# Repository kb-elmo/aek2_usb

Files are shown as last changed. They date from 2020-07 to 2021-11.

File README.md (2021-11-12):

# AEK II USB

[][cc-by-nc-sa]
<a href="https://ko-fi.com/kb_elmo">kofibadge</a>

## This project is completed and will not get updated anymore.

#### QMK compatible drop-in replacement PCB for the Apple Extended Keyboard II
The PCB is built entirely with THT parts to keep a somewhat "vintage" look to it and it uses the fullsize 40-pin DIP package ATmega32A.
The controller is placed in the exact same location as the one on the original PCB.




### Partslist
Most of the parts in this list are just examples and they can be replaced with any component with the same specs.  
They don't have to be from any specific manufacturer or brand to work on this board.

The USB breakout PCB/Daughterboard is NOT included in this repo. You will have to find one yourself.  
Pretty much any kind of breakout board that has usable VCC, GND, D+ and D- pins should work for this.  
Example: https://www.adafruit.com/product/1764

|Count|Part|Designator|Octopart URL|
|-|-|-|-|
|1|ATmega32A 40 pin DIP (32L works too)|U1|[Atmega32a-pu](https://octopart.com/atmega32a-pu-microchip-77760288)|
|1|40 pin DIP socket (optional but highly recommended)|U1|[TE Connectivity 1-2199299-5](https://octopart.com/1-2199299-5-te+connectivity-34963610)|
|1|2x3 pin header 2.54mm (for ISP flashing)|AVR1|[Würth 61200621721](https://octopart.com/61200621721-würth+elektronik-32855457)| 
|1|JST PH 2mm 4pin connector + cable|J1, J2|[JST S4B-PH-K-S](https://octopart.com/s4b-ph-k-s+%28lf%29%28sn%29-jst-5373077)|
|1|USB breakout PCB||[Adafruit 1833](https://octopart.com/1833-adafruit+industries-53099556)|
|1|500 mA polyfuse|F1|[Bourns MF-R050](https://octopart.com/mf-r050-bourns-19418)|
|2|6mm momentary push buttons|RESET1, BOOT1|[TE Connectivity 1825910-6](https://octopart.com/1825910-6-te+connectivity-42270338)|
|1|16 MHz quarz crystal|XTAL1|[Raltron AS-16.000-18](https://octopart.com/as-16.000-18-raltron+electronics-973373)|
|1|4.7 uF electrolytic capacitor|C1|[Panasonic ECA-1HM4R7I](https://octopart.com/eca-1hm4r7i-panasonic-39478610)|
|2|100 nF ceramic disk capacitor|C2, C3|[Kemet C315C104M5U5TA](https://octopart.com/c315c104m5u5ta-kemet-83288)|
|2|22 pF ceramic disk capacitor|C4, C5|[Kemet C317C220J1G5TA](https://octopart.com/c317c220j1g5ta-kemet-1747641)|
|1|10 kΩ resistor|R4|[Multicomp MF25 10k](https://octopart.com/mf25+10k-multicomp-2697429)|
|2|68 Ω resistor|R2, R3|[Multicomp MF25 68R](https://octopart.com/mf25+68r-multicomp-5364489)|
|4|1.5 kΩ resistor|R1, R5, R6, R7|[Multicomp MF25 1k5](https://octopart.com/mf25+1k5-multicomp-5372506)|
|3|5mm LED (for the lock indicators)|LED1, LED2, LED3|[Vishay TLHG5400](https://octopart.com/tlhg5400-vishay-39403037)|
|2|3.6 V zener diode (DO-35 BZX55C3V6)|D1, D2|[ON Semiconductor BZX85C3V6](https://octopart.com/bzx85c3v6-on+semiconductor-84409073)|
|105|universal switching diode (DO-35 1N4148)|D3-D107|[ON Semiconductor 1N4148](https://octopart.com/1n4148-on+semiconductor-6807167)|

#### Some pictures of the first finished PCB
(https://i.imgur.com/3325BHB.jpg) (https://i.imgur.com/cYwRUWX.jpg)
(https://i.imgur.com/b2IuvLg.jpg) (https://i.imgur.com/vxiDwE3.jpg)
(https://i.imgur.com/lfABr6a.jpg) (https://i.imgur.com/BY7TV2w.jpg)

---
This work is licensed under a
[Creative Commons Attribution-NonCommercial-ShareAlike 4.0 International License][cc-by-nc-sa].

[][cc-by-nc-sa]

[cc-by-nc-sa]: http://creativecommons.org/licenses/by-nc-sa/4.0/
[cc-by-nc-sa-image]: https://licensebuttons.net/l/by-nc-sa/4.0/88x31.png
[cc-by-nc-sa-shield]: https://img.shields.io/badge/License-CC%20BY--NC--SA%204.0-lightgrey.svg

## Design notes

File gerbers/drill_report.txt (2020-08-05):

Drill report for aek2_usb.kicad_pcb
Created on Wed Aug  5 12:53:25 2020

Copper Layer Stackup:
    =============================================================
    L1 :  F.Cu                      front
    L2 :  B.Cu                      back

Drill file 'aek2_usb.drl' contains
    plated through holes:
    =============================================================
    T1  0.75mm  0.030"  (8 holes)
    T2  0.80mm  0.031"  (280 holes)
    T3  0.90mm  0.035"  (6 holes)
    T4  1.00mm  0.039"  (8 holes)
    T5  1.10mm  0.043"  (8 holes)
    T6  1.47mm  0.058"  (210 holes)
    T7  4.00mm  0.157"  (2 holes)

    Total plated holes count 522

Not plated through holes are merged with plated holes
    unplated through holes:
    =============================================================

    Total unplated holes count 0

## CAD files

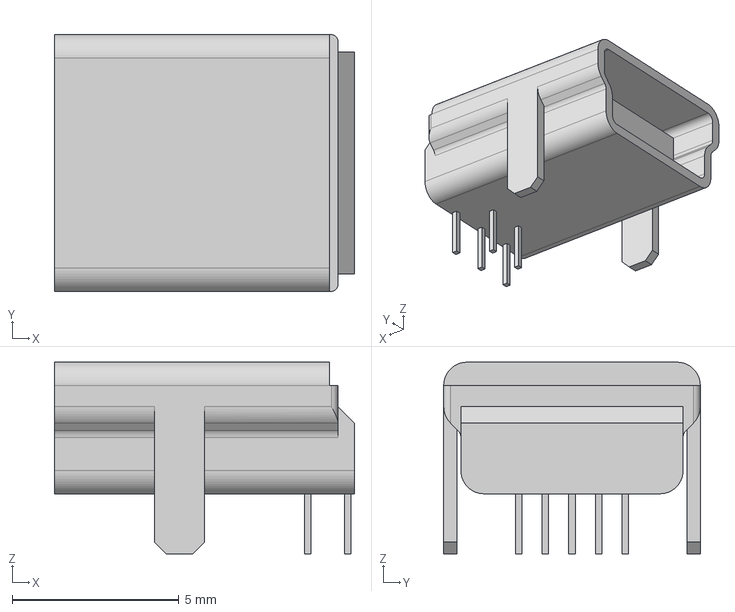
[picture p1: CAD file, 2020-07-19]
custom_parts/Molex-0548190519.step
9.00 x 7.70 x 5.75 mm

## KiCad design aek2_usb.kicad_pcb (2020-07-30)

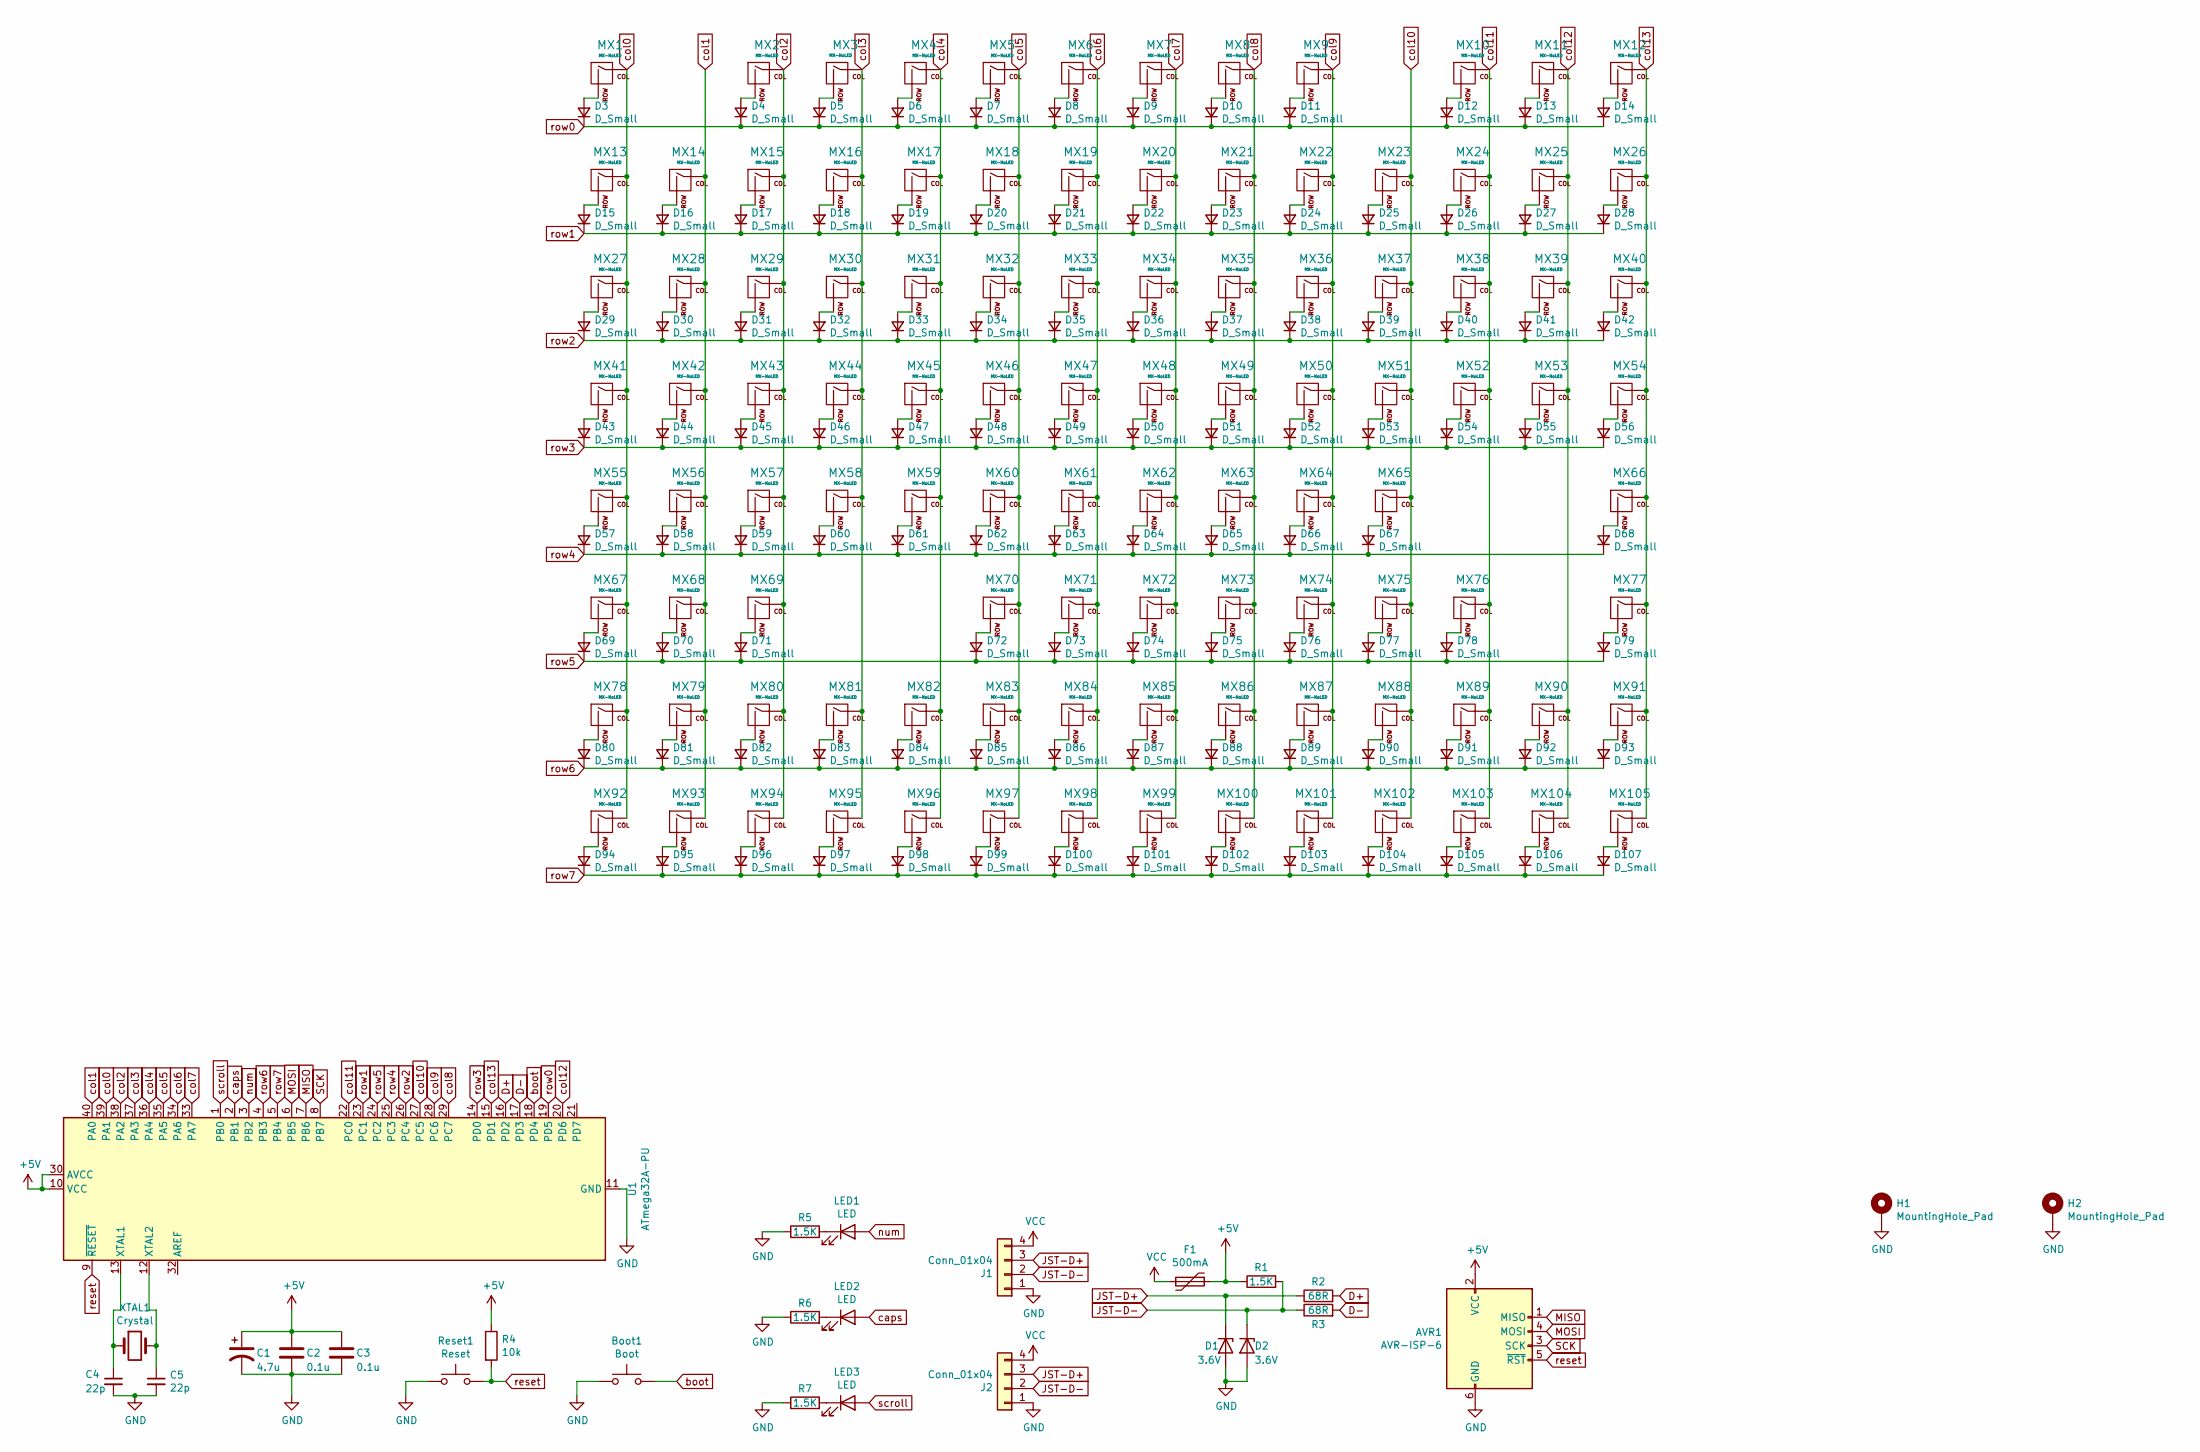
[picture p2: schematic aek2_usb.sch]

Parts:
AVR1: AVR-ISP-6; PinHeader_2x03_P2.54mm_Horizontal
Boot1: Boot; SW_PUSH_6mm
C1: 4.7u; CP_Radial_D5.0mm_P2.50mm
C2, C3: 0.1u; C_Disc_D3.0mm_W2.0mm_P2.50mm
C4, C5: 22p; C_Disc_D6.0mm_W2.5mm_P5.00mm
D1, D2: 3.6V; D_DO-35_SOD27_P7.62mm_Horizontal
D3, D4, D5, D6, D7, D8, D9, D10, D11, D12, D13, D14, D15, D16, D17, D18, D19, D20, D21, D22, D23, D24, D25, D26, D27, D28, D29, D30, D31, D32, D33, D34, D35, D36, D37, D38, D39, D40, D41, D42, D43, D44, D45, D46, D47, D48, D49, D50, D51, D52, D53, D54, D55, D56, D57, D58, D59, D60, D61, D62, D63, D64, D65, D66, D67, D68, D69, D70, D71, D72, D73, D74, D75, D76, D77, D78, D79, D80, D81, D82, D83, D84, D85, D86, D87, D88, D89, D90, D91, D92, D93, D94, D95, D96, D97, D98, D99, D100, D101, D102, D103, D104, D105, D106, D107: D_Small; D_DO-35_SOD27_P7.62mm_Horizontal
F1: 500mA; Fuse_Littelfuse_395Series
H1, H2: MountingHole_Pad; screw-hole
J1, J2: Conn_01x04; JST_PH_S4B-PH-K_1x04_P2.00mm_Horizontal
LED1, LED2, LED3: LED; LED_D5.0mm
MX1, MX2, MX3, MX4, MX5, MX6, MX7, MX8, MX9, MX10, MX11, MX12, MX13, MX14, MX15, MX16, MX17, MX18, MX19, MX20, MX21, MX22, MX23, MX24, MX25, MX28, MX29, MX30, MX31, MX32, MX33, MX34, MX35, MX36, MX37, MX38, MX39, MX42, MX43, MX44, MX45, MX46, MX47, MX48, MX49, MX50, MX51, MX52, MX53, MX56, MX57, MX58, MX59, MX60, MX61, MX62, MX63, MX64, MX65, MX70, MX71, MX72, MX73, MX74, MX78, MX79, MX80, MX81, MX82, MX83, MX84, MX85, MX86, MX87, MX88, MX89, MX90, MX91, MX92, MX93, MX94, MX95, MX96, MX97, MX98, MX99, MX101, MX103, MX104, MX105: MX-NoLED; ALPS-1U
MX26, MX100, MX102: MX-NoLED; ALPS-2U
MX27, MX40, MX67, MX69, MX75, MX77: MX-NoLED; ALPS-1.5U
MX41: MX-NoLED; ALPS-1.75U
MX54, MX55: MX-NoLED; ALPS-2.25U
MX66: MX-NoLED; ALPS-2.75U
MX68, MX76: MX-NoLED; ALPS-1.25U
R1, R5, R6, R7: 1.5K; R_Axial_DIN0207_L6.3mm_D2.5mm_P10.16mm_Horizontal
R2, R3: 68R; R_Axial_DIN0207_L6.3mm_D2.5mm_P10.16mm_Horizontal
R4: 10k; R_Axial_DIN0207_L6.3mm_D2.5mm_P10.16mm_Horizontal
Reset1: Reset; SW_PUSH_6mm
U1: ATmega32A-PU; DIP-40_W15.24mm_Socket
XTAL1: Crystal; Crystal_HC49-4H_Vertical

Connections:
+5V: AVR1.2 (VCC), C1.1, C2.1, C3.1, F1.1, R1.1, R4.1, U1.10 (VCC), U1.30 (AVCC)
D+: R2.2, U1.16 (PD2)
D-: R3.2, U1.17 (PD3)
GND: AVR1.6 (GND), Boot1.1, C1.2, C2.2, C3.2, C4.2, C5.2, D1.2 (A), D2.2 (A), H1.1, H2.1, J1.1, J2.1, R5.1, R6.1, R7.1, Reset1.1, U1.11 (GND), U1.31 (GND)
JST-D+: D1.1 (K), J1.3, J2.3, R2.1
JST-D-: D2.1 (K), J1.2, J2.2, R1.2, R3.1
MISO: AVR1.1 (MISO), U1.7 (PB6)
MOSI: AVR1.4 (MOSI), U1.6 (PB5)
unnamed: C4.1, U1.13 (XTAL1), XTAL1.1
unnamed: C5.1, U1.12 (XTAL2), XTAL1.2
unnamed: D3.2 (A), MX1.2 (ROW)
unnamed: D4.2 (A), MX2.2 (ROW)
unnamed: D5.2 (A), MX3.2 (ROW)
unnamed: D6.2 (A), MX4.2 (ROW)
unnamed: D7.2 (A), MX5.2 (ROW)
unnamed: D8.2 (A), MX6.2 (ROW)
unnamed: D9.2 (A), MX7.2 (ROW)
unnamed: D10.2 (A), MX8.2 (ROW)
unnamed: D11.2 (A), MX9.2 (ROW)
unnamed: D12.2 (A), MX10.2 (ROW)
unnamed: D13.2 (A), MX11.2 (ROW)
unnamed: D14.2 (A), MX12.2 (ROW)
unnamed: D15.2 (A), MX13.2 (ROW)
unnamed: D16.2 (A), MX14.2 (ROW)
unnamed: D17.2 (A), MX15.2 (ROW)
unnamed: D18.2 (A), MX16.2 (ROW)
unnamed: D19.2 (A), MX17.2 (ROW)
unnamed: D20.2 (A), MX18.2 (ROW)
unnamed: D21.2 (A), MX19.2 (ROW)
unnamed: D22.2 (A), MX20.2 (ROW)
unnamed: D23.2 (A), MX21.2 (ROW)
unnamed: D24.2 (A), MX22.2 (ROW)
unnamed: D25.2 (A), MX23.2 (ROW)
unnamed: D26.2 (A), MX24.2 (ROW)
unnamed: D27.2 (A), MX25.2 (ROW)
unnamed: D28.2 (A), MX26.2 (ROW)
unnamed: D29.2 (A), MX27.2 (ROW)
unnamed: D30.2 (A), MX28.2 (ROW)
unnamed: D31.2 (A), MX29.2 (ROW)
unnamed: D32.2 (A), MX30.2 (ROW)
unnamed: D33.2 (A), MX31.2 (ROW)
unnamed: D34.2 (A), MX32.2 (ROW)
unnamed: D35.2 (A), MX33.2 (ROW)
unnamed: D36.2 (A), MX34.2 (ROW)
unnamed: D37.2 (A), MX35.2 (ROW)
unnamed: D38.2 (A), MX36.2 (ROW)
unnamed: D39.2 (A), MX37.2 (ROW)
unnamed: D40.2 (A), MX38.2 (ROW)
unnamed: D41.2 (A), MX39.2 (ROW)
unnamed: D42.2 (A), MX40.2 (ROW)
unnamed: D43.2 (A), MX41.2 (ROW)
unnamed: D44.2 (A), MX42.2 (ROW)
unnamed: D45.2 (A), MX43.2 (ROW)
unnamed: D46.2 (A), MX44.2 (ROW)
unnamed: D47.2 (A), MX45.2 (ROW)
unnamed: D48.2 (A), MX46.2 (ROW)
unnamed: D49.2 (A), MX47.2 (ROW)
unnamed: D50.2 (A), MX48.2 (ROW)
unnamed: D51.2 (A), MX49.2 (ROW)
unnamed: D52.2 (A), MX50.2 (ROW)
unnamed: D53.2 (A), MX51.2 (ROW)
unnamed: D54.2 (A), MX52.2 (ROW)
unnamed: D55.2 (A), MX53.2 (ROW)
unnamed: D56.2 (A), MX54.2 (ROW)
unnamed: D57.2 (A), MX55.2 (ROW)
unnamed: D58.2 (A), MX56.2 (ROW)
unnamed: D59.2 (A), MX57.2 (ROW)
unnamed: D60.2 (A), MX58.2 (ROW)
unnamed: D61.2 (A), MX59.2 (ROW)
unnamed: D62.2 (A), MX60.2 (ROW)
unnamed: D63.2 (A), MX61.2 (ROW)
unnamed: D64.2 (A), MX62.2 (ROW)
unnamed: D65.2 (A), MX63.2 (ROW)
unnamed: D66.2 (A), MX64.2 (ROW)
unnamed: D67.2 (A), MX65.2 (ROW)
unnamed: D68.2 (A), MX66.2 (ROW)
unnamed: D69.2 (A), MX67.2 (ROW)
unnamed: D70.2 (A), MX68.2 (ROW)
unnamed: D71.2 (A), MX69.2 (ROW)
unnamed: D72.2 (A), MX70.2 (ROW)
unnamed: D73.2 (A), MX71.2 (ROW)
unnamed: D74.2 (A), MX72.2 (ROW)
unnamed: D75.2 (A), MX73.2 (ROW)
unnamed: D76.2 (A), MX74.2 (ROW)
unnamed: D77.2 (A), MX75.2 (ROW)
unnamed: D78.2 (A), MX76.2 (ROW)
unnamed: D79.2 (A), MX77.2 (ROW)
unnamed: D80.2 (A), MX78.2 (ROW)
unnamed: D81.2 (A), MX79.2 (ROW)
unnamed: D82.2 (A), MX80.2 (ROW)
unnamed: D83.2 (A), MX81.2 (ROW)
unnamed: D84.2 (A), MX82.2 (ROW)
unnamed: D85.2 (A), MX83.2 (ROW)
unnamed: D86.2 (A), MX84.2 (ROW)
unnamed: D87.2 (A), MX85.2 (ROW)
unnamed: D88.2 (A), MX86.2 (ROW)
unnamed: D89.2 (A), MX87.2 (ROW)
unnamed: D90.2 (A), MX88.2 (ROW)
unnamed: D91.2 (A), MX89.2 (ROW)
unnamed: D92.2 (A), MX90.2 (ROW)
unnamed: D93.2 (A), MX91.2 (ROW)
unnamed: D94.2 (A), MX92.2 (ROW)
unnamed: D95.2 (A), MX93.2 (ROW)
unnamed: D96.2 (A), MX94.2 (ROW)
unnamed: D97.2 (A), MX95.2 (ROW)
unnamed: D98.2 (A), MX96.2 (ROW)
unnamed: D99.2 (A), MX97.2 (ROW)
unnamed: D100.2 (A), MX98.2 (ROW)
unnamed: D101.2 (A), MX99.2 (ROW)
unnamed: D102.2 (A), MX100.2 (ROW)
unnamed: D103.2 (A), MX101.2 (ROW)
unnamed: D104.2 (A), MX102.2 (ROW)
unnamed: D105.2 (A), MX103.2 (ROW)
unnamed: D106.2 (A), MX104.2 (ROW)
unnamed: D107.2 (A), MX105.2 (ROW)
unnamed: LED1.1 (K), R5.2
unnamed: LED2.1 (K), R6.2
unnamed: LED3.1 (K), R7.2
SCK: AVR1.3 (SCK), U1.8 (PB7)
VCC: F1.2, J1.4, J2.4
boot: Boot1.2, U1.18 (PD4)
caps: LED2.2 (A), U1.2 (PB1)
col0: MX1.1 (COL), MX13.1 (COL), MX27.1 (COL), MX41.1 (COL), MX55.1 (COL), MX67.1 (COL), MX78.1 (COL), MX92.1 (COL), U1.39 (PA1)
col1: MX14.1 (COL), MX28.1 (COL), MX42.1 (COL), MX56.1 (COL), MX68.1 (COL), MX79.1 (COL), MX93.1 (COL), U1.40 (PA0)
col2: MX2.1 (COL), MX15.1 (COL), MX29.1 (COL), MX43.1 (COL), MX57.1 (COL), MX69.1 (COL), MX80.1 (COL), MX94.1 (COL), U1.38 (PA2)
col3: MX3.1 (COL), MX16.1 (COL), MX30.1 (COL), MX44.1 (COL), MX58.1 (COL), MX81.1 (COL), MX95.1 (COL), U1.37 (PA3)
col4: MX4.1 (COL), MX17.1 (COL), MX31.1 (COL), MX45.1 (COL), MX59.1 (COL), MX82.1 (COL), MX96.1 (COL), U1.36 (PA4)
col5: MX5.1 (COL), MX18.1 (COL), MX32.1 (COL), MX46.1 (COL), MX60.1 (COL), MX70.1 (COL), MX83.1 (COL), MX97.1 (COL), U1.35 (PA5)
col6: MX6.1 (COL), MX19.1 (COL), MX33.1 (COL), MX47.1 (COL), MX61.1 (COL), MX71.1 (COL), MX84.1 (COL), MX98.1 (COL), U1.34 (PA6)
col7: MX7.1 (COL), MX20.1 (COL), MX34.1 (COL), MX48.1 (COL), MX62.1 (COL), MX72.1 (COL), MX85.1 (COL), MX99.1 (COL), U1.33 (PA7)
col8: MX8.1 (COL), MX21.1 (COL), MX35.1 (COL), MX49.1 (COL), MX63.1 (COL), MX73.1 (COL), MX86.1 (COL), MX100.1 (COL), U1.29 (PC7)
col9: MX9.1 (COL), MX22.1 (COL), MX36.1 (COL), MX50.1 (COL), MX64.1 (COL), MX74.1 (COL), MX87.1 (COL), MX101.1 (COL), U1.28 (PC6)
col10: MX23.1 (COL), MX37.1 (COL), MX51.1 (COL), MX65.1 (COL), MX75.1 (COL), MX88.1 (COL), MX102.1 (COL), U1.27 (PC5)
col11: MX10.1 (COL), MX24.1 (COL), MX38.1 (COL), MX52.1 (COL), MX76.1 (COL), MX89.1 (COL), MX103.1 (COL), U1.22 (PC0)
col12: MX11.1 (COL), MX25.1 (COL), MX39.1 (COL), MX53.1 (COL), MX90.1 (COL), MX104.1 (COL), U1.20 (PD6)
col13: MX12.1 (COL), MX26.1 (COL), MX40.1 (COL), MX54.1 (COL), MX66.1 (COL), MX77.1 (COL), MX91.1 (COL), MX105.1 (COL), U1.15 (PD1)
num: LED1.2 (A), U1.3 (PB2)
reset: AVR1.5 (~RST), R4.2, Reset1.2, U1.9 (~RESET)
row0: D3.1 (K), D4.1 (K), D5.1 (K), D6.1 (K), D7.1 (K), D8.1 (K), D9.1 (K), D10.1 (K), D11.1 (K), D12.1 (K), D13.1 (K), D14.1 (K), U1.19 (PD5)
row1: D15.1 (K), D16.1 (K), D17.1 (K), D18.1 (K), D19.1 (K), D20.1 (K), D21.1 (K), D22.1 (K), D23.1 (K), D24.1 (K), D25.1 (K), D26.1 (K), D27.1 (K), D28.1 (K), U1.23 (PC1)
row2: D29.1 (K), D30.1 (K), D31.1 (K), D32.1 (K), D33.1 (K), D34.1 (K), D35.1 (K), D36.1 (K), D37.1 (K), D38.1 (K), D39.1 (K), D40.1 (K), D41.1 (K), D42.1 (K), U1.26 (PC4)
row3: D43.1 (K), D44.1 (K), D45.1 (K), D46.1 (K), D47.1 (K), D48.1 (K), D49.1 (K), D50.1 (K), D51.1 (K), D52.1 (K), D53.1 (K), D54.1 (K), D55.1 (K), D56.1 (K), U1.14 (PD0)
row4: D57.1 (K), D58.1 (K), D59.1 (K), D60.1 (K), D61.1 (K), D62.1 (K), D63.1 (K), D64.1 (K), D65.1 (K), D66.1 (K), D67.1 (K), D68.1 (K), U1.25 (PC3)
row5: D69.1 (K), D70.1 (K), D71.1 (K), D72.1 (K), D73.1 (K), D74.1 (K), D75.1 (K), D76.1 (K), D77.1 (K), D78.1 (K), D79.1 (K), U1.24 (PC2)
row6: D80.1 (K), D81.1 (K), D82.1 (K), D83.1 (K), D84.1 (K), D85.1 (K), D86.1 (K), D87.1 (K), D88.1 (K), D89.1 (K), D90.1 (K), D91.1 (K), D92.1 (K), D93.1 (K), U1.4 (PB3)
row7: D94.1 (K), D95.1 (K), D96.1 (K), D97.1 (K), D98.1 (K), D99.1 (K), D100.1 (K), D101.1 (K), D102.1 (K), D103.1 (K), D104.1 (K), D105.1 (K), D106.1 (K), D107.1 (K), U1.5 (PB4)
scroll: LED3.2 (A), U1.1 (PB0)

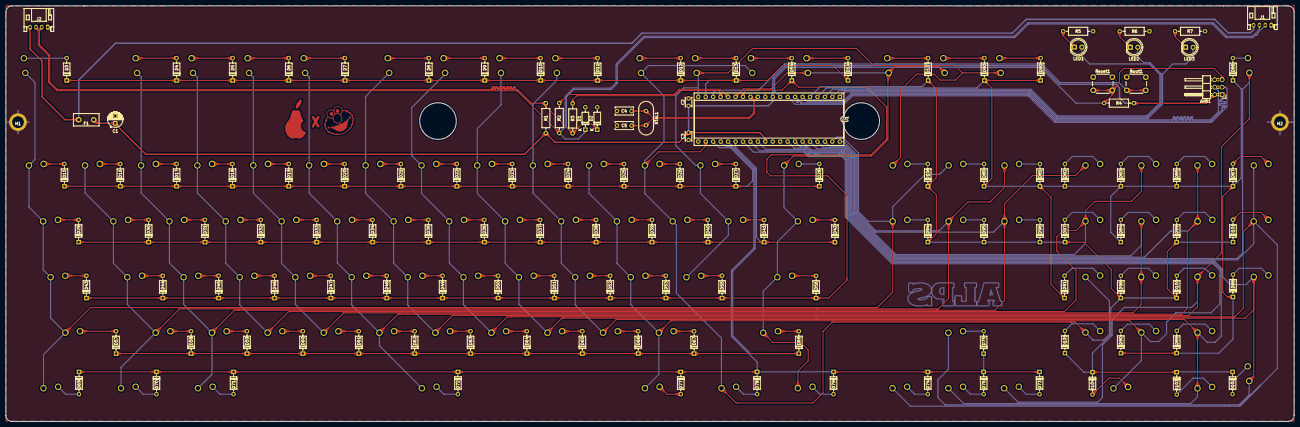
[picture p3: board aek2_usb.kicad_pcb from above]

Board: 2 copper layers, 439.0 x 141.6 mm, 237 parts (0 on the bottom side), 147 nets.

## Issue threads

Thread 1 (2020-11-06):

Partner with another AEK II project for a commercially available version?

quorten, 2020-11-06:
Hello there,

Whoah, I just found your project today but maybe us folks on this other project should have seen it earlier.  Mark from MacEffects (https://maceffects.com/) was interested in designing a AEK II clone with both USB and ADB support, all the mechanical design has already been done, what is left is just the PCB, like, almost your project verbatim.

Me, I'm just an interested community member, but yeah I wanted to reach out by some communication means to start the discussion.  Would you be interested in participating in the MacEffects project?

I noticed your project is licensed for non-commercial use only, so yeah, it's really up to you if you want to permit a license for this particular commercial use.  Mark said that he would be willing to add your expenses to the project total too.

Also, we can find more ways to get you in contact with the community and Mark if you're interested, right now most of the community discussion is happening on the 68kMLA.org forum.

kb-elmo, 2020-11-06:
Hi there,

this sounds like a really nice plan but I don't think that my PCB would be the right choice for this as it is only meant to be compatible with USB and specifically the QMK firmware.
To get it to work with ADB it would require a complete redesign since it is missing all the electronic components that are required for that and I'm not even sure if the QMK firmware would even support ADB (meaning a new firmware would probably be required as well).

Since I never worked with any ADB related stuff I don't think that I would be able to do such a redesign in a reliable good enough way for this project (I'm everything but a professional PCB designer).

quorten, 2020-11-06:
Thanks for your response.  Probably the path Mark's AEK clone project would go down anyways would involve working with his existing professional PCB design contact once he/she finished other PCB design projects he/she is currently busy with.

So, that being said, I'm personally going to end up tinkering around with these designs and hope at least some inspiration from the good ideas in your previous efforts can end up in the commercial product.

Also, my personal, humble opinion about the license for this project.  I recently saw that the Bakeneko 60 open hardware keyboard had to get pulled from GitHub and the group buy idea canceled due to a miscommunication about the licensing of the case design for open-source and commercial reuse, I feel that was a real bummer that had to happen.

So... in light of that, I feel it is worthwhile to put in a little bit of extra effort in clear communications about licensing matters.  Maybe an update to the README indicating you wholeheartedly support independent parties doing a PCB design from scratch to clarify what you mean by "non-commercial use" for this project, and maybe even changing the license of this project to remove the non-commercial use clause, that could be appreciated.

kb-elmo, 2020-11-08:
I'm not exactly sure what you point about the license is?

I certainly don't own any rights for retrofit AEK II PCBs in general.
If someone decides to make his own retrofit PCB for the board then it doesn't fall under the license of this project at all.

quorten, 2020-11-08:
Yeah really, that's really all there is to my point about the license.  Nothing too special other than possibly adding a note to the README stating you don't own any rights to retrofit AEK II PCBs.

Closed 2020-11-06.

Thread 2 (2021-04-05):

tenkeyless option?

kan2k, 2021-04-05:
as title, would be nice

kb-elmo, 2021-04-05:
for what?

You do understand that this is a replacement PCB for the Apple AEK II? A keyboard made in the 80s?
This isn't a complete keyboard and there was no tenkeyless version of the AEK II available.

So there wouldn't be any point in making a TKL version of this.

kan2k, 2021-04-05:
Yeah, I do know that. I am asking because I wanted to mod my AEK2 to a TKL version. Sorry for not being specific on what I am doing.

kb-elmo, 2021-04-05:
you are free to fork and mod this if you want

kan2k, 2021-04-05:
will do thanks

Closed 2021-04-05.

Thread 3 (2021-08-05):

Dumb question

djvs, 2021-08-05:
Any thoughts on ease of supporting more easily/broadly supported Atmega32u4?  Or stm32f?   I think it's just basically changing the controller footprint?  I was staring at your rep in Kicad but I have next to no idea what I'm doing.

kb-elmo, 2021-08-05:
> I think it's just basically changing the controller footprint?

That's definitely not how that works.

Changing the controller would not only require redesigning pretty much all the electroncis on the board but also to rewrite the firmware for the PCB since you can't just use entirely different controllers interchangeably.

I have no plans for doing that.

djvs, 2021-08-05:
There are some alternate PCBs being worked on for this, I just figured if changing the kicad parts was a 5 minute change for you it might simpler.

kb-elmo, 2021-08-05:
> Well, the firmware "rewrite" is a given (though this should be pretty much automatic with QMK, which is the point of using a more common controller)

It absolutely isn't.
Especially not with an STM32 controller.

> but isn't the electronics change basically just changing the termination points of the matrix?

Again. No it isn't.
Atmega32a, Atmega32u4 and _especially_ the STM32 series are completely different controllers that are not compatible with each other in _any_ way.
They require vastly different electronics for the biggest part of the PCB and changing all of that would take quite a bit more than "just 5 minutes".

Maybe inform yourself a bit more about how the electronics of these controllers work.

Closed 2021-08-05.

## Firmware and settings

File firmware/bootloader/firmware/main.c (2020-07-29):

/* Name: main.c
 * Project: USBaspLoader
 * Author: Christian Starkjohann
 * Author: Stephan Baerwolf
 * Creation Date: 2007-12-08
 * Modification Date: 2013-03-31
 * Tabsize: 4
 * Copyright: (c) 2007 by OBJECTIVE DEVELOPMENT Software GmbH
 * License: GNU GPL v2 (see License.txt)
 */

#include "spminterface.h"  /* must be included as first! */

#include "../misc/iofixes.h"

#include <avr/interrupt.h>
#include <avr/pgmspace.h>
#include <avr/wdt.h>
#include <avr/boot.h>
#include <avr/eeprom.h>
#include <util/delay.h>


#if 0
/*
 * 29.09.2012 /  30.09.2012
 * 
 * Since cpufunc.h is not needed in this context and
 * since it is not available in all toolchains, this include
 * becomes deactivated by github issue-report.
 * (In case of trouble it remains in sourcecode for reactivation.)
 * 
 * The autor would like to thank Lena-M for reporting this
 * issue (https://github.com/baerwolf/USBaspLoader/issues/1).
 */
#include <avr/cpufunc.h>
#endif

#include <avr/boot.h>

#include <string.h>



#include "bootloaderconfig.h"

#include "usbdrv/usbdrv.c"
static usbMsgLen_t usbFunctionDescriptor(struct usbRequest *rq) {
  return 0;
}

#ifndef BOOTLOADER_ADDRESS
  #error need to know the bootloaders flash address!
#endif
#define BOOTLOADER_PAGEADDR	(BOOTLOADER_ADDRESS - (BOOTLOADER_ADDRESS % SPM_PAGESIZE))

/* ------------------------------------------------------------------------ */

/* Request constants used by USBasp */
#define USBASP_FUNC_CONNECT         1
#define USBASP_FUNC_DISCONNECT      2
#define USBASP_FUNC_TRANSMIT        3
#define USBASP_FUNC_READFLASH       4
#define USBASP_FUNC_ENABLEPROG      5
#define USBASP_FUNC_WRITEFLASH      6
#define USBASP_FUNC_READEEPROM      7
#define USBASP_FUNC_WRITEEEPROM     8
#define USBASP_FUNC_SETLONGADDRESS  9

// additional USBasp Commands
#define USBASP_FUNC_SETISPSCK	     10
#define USBASP_FUNC_TPI_CONNECT      11
#define USBASP_FUNC_TPI_DISCONNECT   12
#define USBASP_FUNC_TPI_RAWREAD      13
#define USBASP_FUNC_TPI_RAWWRITE     14
#define USBASP_FUNC_TPI_READBLOCK    15
#define USBASP_FUNC_TPI_WRITEBLOCK   16
#define USBASP_FUNC_GETCAPABILITIES 127
/* ------------------------------------------------------------------------ */

#ifndef ulong
#   define ulong    unsigned long
#endif
#ifndef uint
#   define uint     unsigned int
#endif


/* allow compatibility with avrusbboot's bootloaderconfig.h: */
#ifdef BOOTLOADER_INIT
#   define bootLoaderInit()         BOOTLOADER_INIT
#   define bootLoaderExit()
#endif
#ifdef BOOTLOADER_CONDITION
#   define bootLoaderCondition()    BOOTLOADER_CONDITION
#endif

/* device compatibility: */
#ifndef GICR    /* ATMega*8 don't have GICR, use MCUCR instead */
#   define GICR     MCUCR
#endif

/* ------------------------------------------------------------------------ */

#if (FLASHEND) > 0xffff /* we need long addressing */
#   define CURRENT_ADDRESS  currentAddress.l
#   define addr_t           ulong
#else
#   define CURRENT_ADDRESS  currentAddress.w[0]
#   define addr_t           uint
#endif

typedef union longConverter{
    addr_t  l;
    uint    w[sizeof(addr_t)/2];
    uchar   b[sizeof(addr_t)];
}longConverter_t;


#define __IMPLEMENT_PRESERVE_WATCHDOG	((PRESERVE_WATCHDOG) && (!(USE_EXCESSIVE_ASSEMBLER)) && ((NEED_WATCHDOG) || (defined(__MCUCSR_COMPATMODE))))
#if (__IMPLEMENT_PRESERVE_WATCHDOG)
static uint8_t __original_WDTCR;
#endif

#if (BOOTLOADER_CAN_EXIT)
#	if (BOOTLOADER_LOOPCYCLES_TIMEOUT)
#		if (BOOTLOADER_LOOPCYCLES_TIMEOUT < 256)
#			if ((HAVE_UNPRECISEWAIT))
	 register uint8_t timeout_remaining __asm__("r2");
#			else
static volatile uint8_t timeout_remaining;
#			endif
#		else
static volatile uint16_t timeout_remaining;
#		endif
#	endif

#	define stayinloader_initialValue 0xfe
#	if ((HAVE_UNPRECISEWAIT))
/* here we have to assume we need to optimize for every byte */
	 register uint8_t stayinloader __asm__("r17");
#	else
static volatile uint8_t stayinloader;
#	endif
#endif

static longConverter_t  	currentAddress; /* in bytes */
static uchar            	bytesRemaining;
static uchar            	isLastPage;
#if HAVE_EEPROM_PAGED_ACCESS
static uchar            	currentRequest;
#else
static const uchar      	currentRequest = 0;
#endif

static const uchar  signatureBytes[4] = {
#ifdef SIGNATURE_BYTES
    SIGNATURE_BYTES
#elif defined (__AVR_ATmega8535__)
    0x1e, 0x93, 0x08, 0
#elif defined (__AVR_ATmega8__) || defined (__AVR_ATmega8A__) || defined (__AVR_ATmega8HVA__)
    0x1e, 0x93, 0x07, 0
#elif defined (__AVR_ATmega16__)
    0x1e, 0x94, 0x03, 0
#elif defined (__AVR_ATmega32__)
    0x1e, 0x95, 0x02, 0
#elif defined (__AVR_ATmega48__) || defined (__AVR_ATmega48A__)
    #error ATmega48 does not support bootloaders!
    0x1e, 0x92, 0x05, 0
#elif defined (__AVR_ATmega48PA__) || defined (__AVR_ATmega48P__)
    #error ATmega48P does not support bootloaders!
    0x1e, 0x92, 0x0A, 0
#elif defined (__AVR_ATmega88__) || defined (__AVR_ATmega88A__)
    0x1e, 0x93, 0x0a, 0
#elif defined (__AVR_ATmega88PA__) || defined (__AVR_ATmega88P__)
    0x1e, 0x93, 0x0F, 0
#elif defined (__AVR_ATmega162__)
    0x1e, 0x94, 0x04, 0
#elif defined (__AVR_ATmega164A__)
    0x1e, 0x94, 0x0f, 0
#elif defined (__AVR_ATmega164P__) || defined (__AVR_ATmega164PA__)
    0x1e, 0x94, 0x0a, 0
#elif defined (__AVR_ATmega168__) || defined (__AVR_ATmega168A__)
    0x1e, 0x94, 0x06, 0
#elif defined (__AVR_ATmega168PA__) || defined (__AVR_ATmega168P__)
    0x1e, 0x94, 0x0B, 0
#elif defined (__AVR_ATmega324A__)
    0x1e, 0x95, 0x15, 0
#elif defined (__AVR_ATmega324P__)
    0x1e, 0x95, 0x08, 0
#elif defined (__AVR_ATmega324PA__)
    0x1e, 0x95, 0x11, 0
#elif defined (__AVR_ATmega328__)
    0x1e, 0x95, 0x14, 0
#elif defined (__AVR_ATmega328P__)
    0x1e, 0x95, 0x0f, 0
#elif defined (__AVR_ATmega640__)
    0x1e, 0x96, 0x08, 0
#elif defined (__AVR_ATmega644__) || defined (__AVR_ATmega644A__)
    0x1e, 0x96, 0x09, 0
#elif defined (__AVR_ATmega644P__) || defined (__AVR_ATmega644PA__)
    0x1e, 0x96, 0x0a, 0
#elif defined (__AVR_ATmega128__)
    0x1e, 0x97, 0x02, 0
#elif defined (__AVR_ATmega1280__)
    0x1e, 0x97, 0x03, 0
#elif defined (__AVR_ATmega1281__)
    0x1e, 0x97, 0x04, 0
#elif defined (__AVR_ATmega1284__)
    0x1e, 0x97, 0x06, 0
#elif defined (__AVR_ATmega1284P__)
    0x1e, 0x97, 0x05, 0
#elif defined (__AVR_ATmega2560__)
    0x1e, 0x98, 0x01, 0
#elif defined (__AVR_ATmega2561__)
    0x1e, 0x98, 0x02, 0
#else
#   if (defined(SIGNATURE_0) && defined(SIGNATURE_1) && defined(SIGNATURE_2))
#     warning "Device signature is not known - using AVR Libc suggestion..."
    SIGNATURE_0, SIGNATURE_1, SIGNATURE_2, 0
#   else
#     error "Device signature is not known, please edit main.c!"
#   endif
#endif
};

/* ------------------------------------------------------------------------ */

#if (HAVE_BOOTLOADERENTRY_FROMSOFTWARE)
void __attribute__ ((section(".init3"),naked,used,no_instrument_function)) __BOOTLOADERENTRY_FROMSOFTWARE__bootup_investigate_RAMEND(void);
void __BOOTLOADERENTRY_FROMSOFTWARE__bootup_investigate_RAMEND(void) {
  asm volatile (
    "in		%[mcucsrval]	,	%[mcucsrio]\n\t"
    "ldi	r29		,	%[ramendhi]\n\t"
    "ldi	r28		,	%[ramendlo]\n\t"
#if (FLASHEND>131071)
    "ld		%[result]	,	Y+\n\t"
    "cpi	%[result]	,	%[bootaddrhi]\n\t"
    "brne	__BOOTLOADERENTRY_FROMSOFTWARE__bootup_investigate_RAMEND_mismatch%=\n\t"
#endif
    "ld		%[result]	,	Y+\n\t"
    "cpi	%[result]	,	%[bootaddrme]\n\t"
    "ld		%[result]	,	Y+\n\t"
    "breq	__BOOTLOADERENTRY_FROMSOFTWARE__bootup_investigate_RAMEND_done%=\n\t"

    "__BOOTLOADERENTRY_FROMSOFTWARE__bootup_investigate_RAMEND_mismatch%=:\n\t"
    "ldi	%[result]	,	0xff\n\t"

    "__BOOTLOADERENTRY_FROMSOFTWARE__bootup_investigate_RAMEND_done%=:\n\t"
    : [result]		"=a" (__BOOTLOADERENTRY_FROMSOFTWARE__bootup_RAMEND_doesmatch),
      [mcucsrval]	"=a" (__BOOTLOADERENTRY_FROMSOFTWARE__bootup_MCUCSR)
    : [mcucsrio]	"I"  (_SFR_IO_ADDR(MCUCSR)),
#if (FLASHEND>131071)
      [ramendhi]	"M" (((RAMEND - 2) >> 8) & 0xff),
      [ramendlo]	"M" (((RAMEND - 2) >> 0) & 0xff),
      [bootaddrhi]	"M" (((__BOOTLOADERENTRY_FROMSOFTWARE__EXPECTEDADDRESS) >>16) & 0xff),
#else
      [ramendhi]	"M" (((RAMEND - 1) >> 8) & 0xff),
      [ramendlo]	"M" (((RAMEND - 1) >> 0) & 0xff),
#endif
      [bootaddrme]	"M" (((__BOOTLOADERENTRY_FROMSOFTWARE__EXPECTEDADDRESS) >> 8) & 0xff)
    
  );
}
#endif

#if (USE_BOOTUP_CLEARRAM)
/*
* Under normal circumstances, RESET will not clear contents of RAM.
* As always, if you want it done - do it yourself...
*/
void __attribute__ ((section(".init3"),naked,used,no_instrument_function)) __func_clearram(void);
void __func_clearram(void) {
  extern size_t __bss_end;
  asm volatile (
    "__clearram:\n\t"
#if (!(HAVE_BOOTLOADERENTRY_FROMSOFTWARE))
    "ldi r29, %[ramendhi]\n\t"
    "ldi r28, %[ramendlo]\n\t"
#endif
    "__clearramloop%=:\n\t"
    "st -Y , __zero_reg__\n\t"
    "cp r28, %A[bssend]\n\t"
    "cpc r29, %B[bssend]\n\t"
    "brne __clearramloop%=\n\t"
    :
    : [ramendhi] "M" (((RAMEND+1)>>8) & 0xff),
      [ramendlo] "M" (((RAMEND+1)>>0) & 0xff),
      [bssend] "r" (&__bss_end)
    : "memory"
      );
}
#endif

#if (!USE_EXCESSIVE_ASSEMBLER) || (!(defined (__AVR_ATmega8__) || defined (__AVR_ATmega8A__) || defined (__AVR_ATmega8HVA__)))
static void (*nullVector)(void) __attribute__((__noreturn__));
#endif

#if (USE_EXCESSIVE_ASSEMBLER) && (defined (__AVR_ATmega8__) || defined (__AVR_ATmega8A__) || defined (__AVR_ATmega8HVA__))
static void __attribute__((naked,__noreturn__)) leaveBootloader(void);
static void leaveBootloader(void) {
  asm  volatile  (
  "cli\n\t"
  "sbi		%[usbddr],	%[usbminus]\n\t"  
  "cbi		%[port],	%[bit]\n\t"
  "out		%[usbintrenab],	__zero_reg__\n\t"
  "out		%[usbintrcfg],	__zero_reg__\n\t"
  "ldi		r31,		%[ivce]\n\t"
  "out		%[mygicr],	r31\n\t"
  "out		%[mygicr],	__zero_reg__\n\t"  
  "rjmp		nullVector\n\t"
  :
  : [port]        "I" (_SFR_IO_ADDR(PIN_PORT(JUMPER_PORT))),
    [bit]         "I" (PIN(JUMPER_PORT, JUMPER_BIT)),
    [usbintrenab] "I" (_SFR_IO_ADDR(USB_INTR_ENABLE)),
    [usbintrcfg]  "I" (_SFR_IO_ADDR(USB_INTR_CFG)),
    [usbddr]      "I" (_SFR_IO_ADDR(USBDDR)),
    [usbminus]    "I" (USBMINUS),
    [mygicr]      "I" (_SFR_IO_ADDR(GICR)),	      
    [ivce]        "I" (1<<IVCE)
);
}
#else
static void __attribute__((__noreturn__)) leaveBootloader(void);
static void leaveBootloader(void) {
    DBG1(0x01, 0, 0);
    cli();
    usbDeviceDisconnect();
    bootLoaderExit();
    USB_INTR_ENABLE = 0;
    USB_INTR_CFG = 0;       /* also reset config bits */
    GICR = (1 << IVCE);     /* enable change of interrupt vectors */
    GICR = (0 << IVSEL);    /* move interrupts to application flash section */

/* restore the original watchdog timer if necessary */
#if (__IMPLEMENT_PRESERVE_WATCHDOG)
    if (__original_WDTCR & _BV(WDE)) {
      __original_WDTCR &= ~(_BV(WDCE));
      wdt_reset();
      WDTCR |= (_BV(WDCE)) | (_BV(WDE));
      WDTCR  = __original_WDTCR;
      wdt_reset();
    }
#endif
/*
 * There seems to be another funny compiler Bug.
 * When gcc is using "eicall" opcode it forgets to modify EIND.
 * On devices with large flash memory there are some target address bits
 * missing. In this case some zero bits...
 */
#if (defined(EIND) && ((FLASHEND)>131071))
  EIND=0;
#endif
/* We must go through a global function pointer variable instead of writing
 *  ((void (*)(void))0)();
 * because the compiler optimizes a constant 0 to "rcall 0" which is not
 * handled correctly by the assembler.
 */
    nullVector();
}
#endif

/* ------------------------------------------------------------------------ */


uchar usbFunctionSetup_USBASP_FUNC_TRANSMIT(usbRequest_t *rq) {
  uchar rval = 0;
  usbWord_t address;
  address.bytes[1] = rq->wValue.bytes[1];
  address.bytes[0] = rq->wIndex.bytes[0];

  if(rq->wValue.bytes[0] == 0x30){        /* read signature */
    rval = rq->wIndex.bytes[0] & 3;
    rval = signatureBytes[rval];
#if HAVE_READ_LOCK_FUSE
#if defined (__AVR_ATmega8535__) || 					\
    defined (__AVR_ATmega8__) || defined (__AVR_ATmega8A__) || 		\
    defined (__AVR_ATmega16__) || defined (__AVR_ATmega32__)
  }else if(rq->wValue.bytes[0] == 0x58 && rq->wValue.bytes[1] == 0x00){  /* read lock bits */
      rval = boot_lock_fuse_bits_get(GET_LOCK_BITS);
  }else if(rq->wValue.bytes[0] == 0x50 && rq->wValue.bytes[1] == 0x00){  /* read lfuse bits */
      rval = boot_lock_fuse_bits_get(GET_LOW_FUSE_BITS);
  }else if(rq->wValue.bytes[0] == 0x58 && rq->wValue.bytes[1] == 0x08){  /* read hfuse bits */
      rval = boot_lock_fuse_bits_get(GET_HIGH_FUSE_BITS);

#elif defined (__AVR_ATmega48__)   || defined (__AVR_ATmega48A__)   || defined (__AVR_ATmega48P__)   || defined (__AVR_ATmega48PA__)  ||  \
defined (__AVR_ATmega88__)   || defined (__AVR_ATmega88A__)   || defined (__AVR_ATmega88P__)   || defined (__AVR_ATmega88PA__)  ||  \
defined (__AVR_ATmega162__)  || 												      \
defined (__AVR_ATmega164A__) || defined (__AVR_ATmega164P__)  || 								      \
defined (__AVR_ATmega168__)  || defined (__AVR_ATmega168A__)  || defined (__AVR_ATmega168P__)  || defined (__AVR_ATmega168PA__) ||  \
defined (__AVR_ATmega324A__) || defined (__AVR_ATmega324P__)  ||								      \
defined (__AVR_ATmega328__)  || defined (__AVR_ATmega328P__)  ||								      \
defined (__AVR_ATmega640__)  ||													\
defined (__AVR_ATmega644__)  || defined (__AVR_ATmega644A__)  || defined (__AVR_ATmega644P__) || defined (__AVR_ATmega644PA__)  ||  \
defined (__AVR_ATmega128__)  ||													      \
defined (__AVR_ATmega1280__) ||													\
defined (__AVR_ATmega1281__) ||													\
defined (__AVR_ATmega1284__) || defined (__AVR_ATmega1284P__)  ||													\
defined (__AVR_ATmega2560__) ||													\
defined (__AVR_ATmega2561__)
  }else if(rq->wValue.bytes[0] == 0x58 && rq->wValue.bytes[1] == 0x00){  /* read lock bits */
      rval = boot_lock_fuse_bits_get(GET_LOCK_BITS);
  }else if(rq->wValue.bytes[0] == 0x50 && rq->wValue.bytes[1] == 0x00){  /* read lfuse bits */
      rval = boot_lock_fuse_bits_get(GET_LOW_FUSE_BITS);
  }else if(rq->wValue.bytes[0] == 0x58 && rq->wValue.bytes[1] == 0x08){  /* read hfuse bits */
      rval = boot_lock_fuse_bits_get(GET_HIGH_FUSE_BITS);
  }else if(rq->wValue.bytes[0] == 0x50 && rq->wValue.bytes[1] == 0x08){  /* read efuse bits */
      rval = boot_lock_fuse_bits_get(GET_EXTENDED_FUSE_BITS );
#else
  #warning "HAVE_READ_LOCK_FUSE is activated but MCU unknown -> will not support this feature"
#endif
#endif
#if HAVE_FLASH_BYTE_READACCESS
  }else if(rq->wValue.bytes[0] == 0x20){  /* read FLASH low  byte */
#if ((FLASHEND) > 65535)
      rval = pgm_read_byte_far((((addr_t)address.word)<<1)+0);
#else
      rval = pgm_read_byte((((addr_t)address.word)<<1)+0);
#endif
  }else if(rq->wValue.bytes[0] == 0x28){  /* read FLASH high byte */
#if ((FLASHEND) > 65535)
      rval = pgm_read_byte_far((((addr_t)address.word)<<1)+1);
#else
      rval = pgm_read_byte((((addr_t)address.word)<<1)+1);
#endif
#endif
#if HAVE_EEPROM_BYTE_ACCESS
  }else if(rq->wValue.bytes[0] == 0xa0){  /* read EEPROM byte */
      rval = eeprom_read_byte((void *)address.word);
  }else if(rq->wValue.bytes[0] == 0xc0){  /* write EEPROM byte */
      eeprom_write_byte((void *)address.word, rq->wIndex.bytes[1]);
#endif
#if HAVE_CHIP_ERASE
  }else if(rq->wValue.bytes[0] == 0xac && rq->wValue.bytes[1] == 0x80){  /* chip erase */
      addr_t addr;
#if HAVE_BLB11_SOFTW_LOCKBIT
      for(addr = 0; addr < (addr_t)(BOOTLOADER_PAGEADDR) ; addr += SPM_PAGESIZE) {
#else
      for(addr = 0; addr <= (addr_t)(FLASHEND) ; addr += SPM_PAGESIZE) {
#endif
	  /* wait and erase page */
	  DBG1(0x33, 0, 0);
#   ifndef NO_FLASH_WRITE
	  boot_spm_busy_wait();
	  cli();
	  boot_page_erase(addr);
	  sei();
#   endif
      }
#endif
#if ((HAVE_BOOTLOADER_HIDDENEXITCOMMAND) && (BOOTLOADER_CAN_EXIT))
#	if ((HAVE_BOOTLOADER_HIDDENEXITCOMMAND != 0xac) && \
	    (HAVE_BOOTLOADER_HIDDENEXITCOMMAND != 0x20) && (HAVE_BOOTLOADER_HIDDENEXITCOMMAND != 0x28) && \
	    (HAVE_BOOTLOADER_HIDDENEXITCOMMAND != 0x40) && (HAVE_BOOTLOADER_HIDDENEXITCOMMAND != 0x48) && \
	    (HAVE_BOOTLOADER_HIDDENEXITCOMMAND != 0x4c) && \
	    (HAVE_BOOTLOADER_HIDDENEXITCOMMAND != 0xa0) && \
	    (HAVE_BOOTLOADER_HIDDENEXITCOMMAND != 0xc0) && \
	    (HAVE_BOOTLOADER_HIDDENEXITCOMMAND != 0x58) && \
	    (HAVE_BOOTLOADER_HIDDENEXITCOMMAND != 0x5c) && \
	    (HAVE_BOOTLOADER_HIDDENEXITCOMMAND != 0x30) && \
	    (HAVE_BOOTLOADER_HIDDENEXITCOMMAND != 0xac) && \
	    (HAVE_BOOTLOADER_HIDDENEXITCOMMAND != 0x50) && (HAVE_BOOTLOADER_HIDDENEXITCOMMAND != 0x58) && \
	    (HAVE_BOOTLOADER_HIDDENEXITCOMMAND != 0x38))
  }else if(rq->wValue.bytes[0] == (HAVE_BOOTLOADER_HIDDENEXITCOMMAND)){  /* cause a bootLoaderExit at disconnect */
      stayinloader = 0xf1;  /* we need to be connected - so assume it */
#	endif
#endif
  }else{
      /* ignore all others, return default value == 0 */
  }
        
  return rval;
}


usbMsgLen_t usbFunctionSetup(uchar data[8])
{
usbRequest_t    *rq = (void *)data;
usbMsgLen_t     len = 0;
static uchar    replyBuffer[4];

    usbMsgPtr = (usbMsgPtr_t)replyBuffer;
    if(rq->bRequest == USBASP_FUNC_TRANSMIT){   /* emulate parts of ISP protocol */
        replyBuffer[3] = usbFunctionSetup_USBASP_FUNC_TRANSMIT(rq);
        len = (usbMsgLen_t)4;
    }else if((rq->bRequest == USBASP_FUNC_ENABLEPROG) || (rq->bRequest == USBASP_FUNC_SETISPSCK)){
        /* replyBuffer[0] = 0; is never touched and thus always 0 which means success */
        len = (usbMsgLen_t)1;
    }else if(rq->bRequest >= USBASP_FUNC_READFLASH && rq->bRequest <= USBASP_FUNC_SETLONGADDRESS){
        currentAddress.w[0] = rq->wValue.word;
        if(rq->bRequest == USBASP_FUNC_SETLONGADDRESS){
#if (FLASHEND) > 0xffff
            currentAddress.w[1] = rq->wIndex.word;
#endif
        }else{
            bytesRemaining = rq->wLength.bytes[0];
            /* if(rq->bRequest == USBASP_FUNC_WRITEFLASH) only evaluated during writeFlash anyway */
            isLastPage = rq->wIndex.bytes[1] & 0x02;
#if HAVE_EEPROM_PAGED_ACCESS
            currentRequest = rq->bRequest;
#endif
            len = USB_NO_MSG; /* hand over to usbFunctionRead() / usbFunctionWrite() */
        }

    }else if(rq->bRequest == USBASP_FUNC_DISCONNECT){

#if BOOTLOADER_CAN_EXIT
#	ifdef CONFIG_HAVE__BOOTLOADER_ABORTTIMEOUTONACT
      /* let the main loop know for ever that here was activity */
      stayinloader	   &= (0xfc);
#	else
      stayinloader	   &= (0xfe);
#	endif
#endif
    }else{
        /* ignore: others, but could be USBASP_FUNC_CONNECT */
#if BOOTLOADER_CAN_EXIT
	stayinloader	   |= (0x01);
#endif
    }
    return len;
}

#if (USE_EXCESSIVE_ASSEMBLER) && ((!HAVE_CHIP_ERASE) || (HAVE_ONDEMAND_PAGEERASE)) && (SPM_PAGESIZE <= 256) && (((BOOTLOADER_PAGEADDR>>0)&0xff) == 0)
uchar usbFunctionWrite(uchar *data, uchar len)
{
uchar   isLast;

    DBG1(0x31, (void *)&currentAddress.l, 4);
    if(len > bytesRemaining)
        len = bytesRemaining;
    bytesRemaining -= len;
    isLast = bytesRemaining == 0;
    if(currentRequest >= USBASP_FUNC_READEEPROM){
        uchar i;
        for(i = 0; i < len; i++){
            eeprom_write_byte((void *)(currentAddress.w[0]++), *data++);
        }
    }else{
	asm  volatile  (
	  "sbrc		%[len], 0\n\t"
	  "inc		%[len]\n\t"
"usbFunctionWrite_flashloop:\n\t"
	  "subi		%[len], 2\n\t"
	  "brlo		usbFunctionWrite_finished\n\t"
	  
#if HAVE_BLB11_SOFTW_LOCKBIT
	  "cpi		r31, %[blsaddrhi]\n\t"			/* accelerated BLB11_SOFTW_LOCKBIT check */
	  "brsh		usbFunctionWrite_finished\n\t"
// 	  "brlo		usbFunctionWrite_addrunlock_ok\n\t"
// 	  "brne		usbFunctionWrite_finished\n\t"
// 	  "cpi		r30, %[blsaddrlo]\n\t"
// 	  "brlo		usbFunctionWrite_addrunlock_ok\n\t"
// 	  "rjmp		usbFunctionWrite_finished\n\t"
// "usbFunctionWrite_addrunlock_ok:\n\t"
#endif
	  "rcall	usbFunctionWrite_waitA\n\t"
	  "cli\n\t"						/* r0 or r1 may be __zero_reg__ and may become dangerous nonzero within interrupts */
	  "ld		r0,		X+\n\t"
	  "ld		r1,		X+\n\t"

	  "ldi		r18,		%[pagfillval]\n\t"
	  "rcall	usbFunctionWrite_saveflash\n\t"	/* page fill */

	  "mov		r18,		r30\n\t"
	  "subi		r18,		0xfe\n\t"		/* add with 2 */
	  "andi		r18,		%[pagemask]\n\t"
	  "breq		usbFunctionWrite_pageisfull\n\t"
	  "tst		%[islast]\n\t"
	  "breq		usbFunctionWrite_skippageisfull\n\t"
	  "tst		%[isLastPage]\n\t"
	  "breq		usbFunctionWrite_skippageisfull\n\t"
	  "cpi		%[len],		0\n\t"
	  "brne		usbFunctionWrite_skippageisfull\n\t"

"usbFunctionWrite_pageisfull:\n\t"				/* start writing the page */
	  "ldi		r18,		%[pageraseval]\n\t"
	  "rcall	usbFunctionWrite_saveflash\n\t"	/* page erase */
	  "rcall	usbFunctionWrite_waitA\n\t"

	  "ldi		r18,		%[pagwriteval]\n\t"
	  "rcall	usbFunctionWrite_saveflash\n\t"	/* page write */
	  "rcall	usbFunctionWrite_waitA\n\t"

	  "in		__tmp_reg__,	%[spmcr]\n\t"
	  "sbrs		__tmp_reg__,	%[rwwsbbit]\n\t"
	  "rjmp		usbFunctionWrite_skippageisfull\n\t"
	  "ldi		r18,		%[rwwenrval]\n\t"
	  "rcall	usbFunctionWrite_saveflash\n\t"	/* reenable rww*/
// 	  "rcall	usbFunctionWrite_waitA\n\t"


"usbFunctionWrite_skippageisfull:\n\t"	  
	  "adiw		r30,		0x2\n\t"
	  "rjmp		usbFunctionWrite_flashloop\n\t"

"usbFunctionWrite_saveflash:\n\t"
	  "cli\n\t"
	  "out		%[spmcr],	r18\n\t"
	  "spm\n\t"
	  "clr		__zero_reg__\n\t"			/* if r0 or r1 is __zero_reg__ it may have become inconsisten while page-fill */
	  "sei\n\t"
	  "ret\n\t"

"usbFunctionWrite_waitA:\n\t"
	  "in		__tmp_reg__,	%[spmcr]\n\t"
	  "sbrc		__tmp_reg__,	%[spmenbit]\n\t"
	  "rjmp		usbFunctionWrite_waitA\n\t"
	  "ret\n\t"
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

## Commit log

2020-07-19 change logo
    [aek2_usb.kicad_pcb]
2020-07-29 added firmware
    [aek2_usb.kicad_pcb, aek2_usb.sch]
2020-07-30 added ISO support (UNTESTED!)
    [aek2_usb.kicad_pcb, aek2_usb.sch]
2020-07-30 fix ISO enter position (still untested!)
    [aek2_usb.kicad_pcb]
2020-07-30 add teardrops
    [aek2_usb.kicad_pcb]
2020-07-30 remove ISO support because layout is wrong
    [aek2_usb.kicad_pcb, aek2_usb.sch]
2020-07-30 fix teardrops
    [aek2_usb.kicad_pcb]

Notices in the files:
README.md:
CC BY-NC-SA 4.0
